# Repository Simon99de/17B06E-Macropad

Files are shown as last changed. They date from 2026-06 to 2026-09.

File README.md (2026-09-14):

# 17B06E-Macropad (by Simon99de)
> [!WARNING]
> Please note: The code is no longer being updated on GitHub!
> 
> The project has been moved to [Codeberg](https://codeberg.org/Simon99de/17B06E-Macropad)!

***
Eine deutsche Anleitung findest du auf meiner Website: [Simon99.de](https://simon99.de/blog/17b06e-macropad/)

It is a simple 4x4 (+1) numpad with 6 rotary encoders, 4x4 RGB LEDs, OLED display, and hot-swap keys.

You can customize all 6 encoders and 17 keys however you want. It also supports multiple layers (/pages), which means that a single key can do much more. (That's why the keyboard has 17 keys instead of 16.)

It can be an alternative to various keyboards such as Streamdeck+, Loupdeck Live, etc. if you don't need the screen behind the keys. In addition, the Macropad keyboard does not require any background software to function, which means increased compatibility.

Powered by QMK via Waveshare RP2040-Plus / Raspberry Pi Pico (1).

### What does 17B06E mean?
I chose the name 17B06E-Macropad because it describes everything the Macropad has. 17 Buttons + 6 Encoders. It also has RGB and a small OLED display.
The top button is used to switch profiles, giving you 16 x 4 (or more/less) buttons at your disposal, with the current profile shown on the display.

***

#### The old code is in the V1 branch.

#### But you should go to Codeberg! (link above)

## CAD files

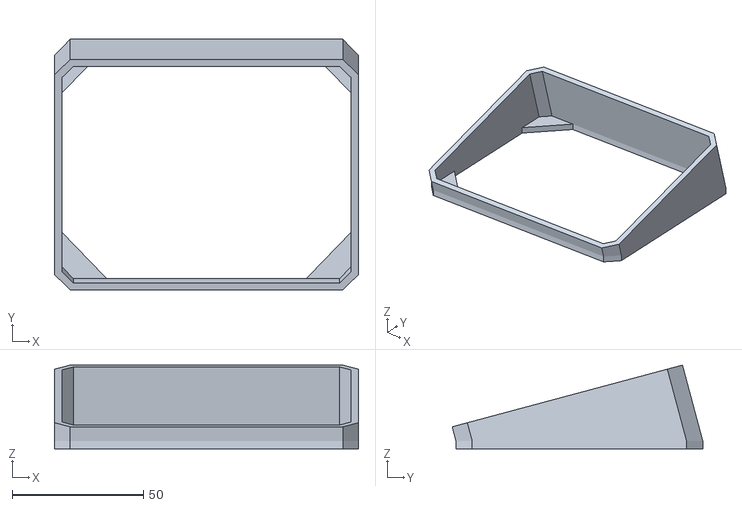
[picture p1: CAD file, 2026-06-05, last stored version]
case/17B06E-Macropad-Case-Foot_v1.stl
116.0 x 95.7 x 32.0

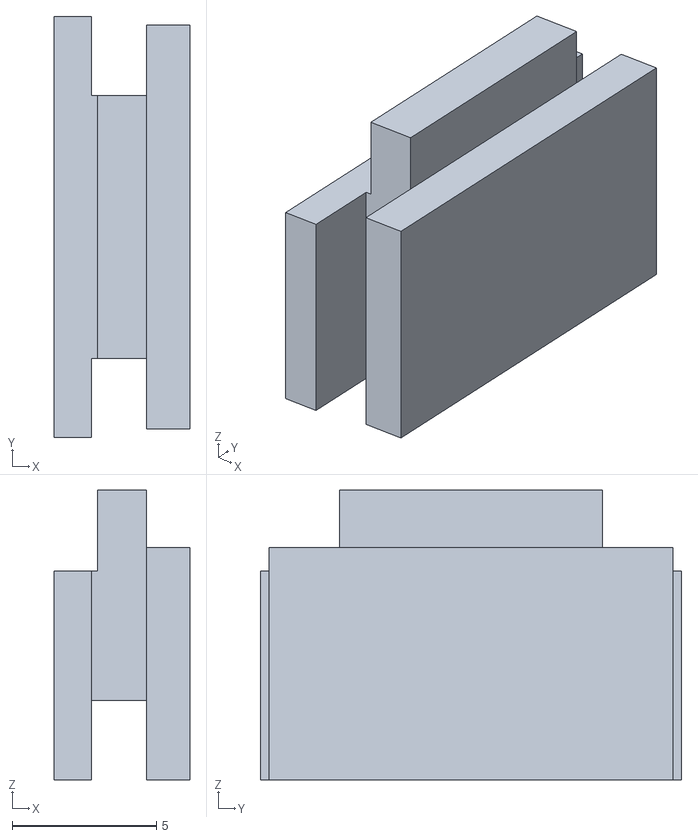
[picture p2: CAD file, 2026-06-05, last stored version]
case/mods/17B06E-Macropad-Case-Mod-USB-c-Cover_v1-hotswap-MCU.stl
4.70 x 14.6 x 10.1

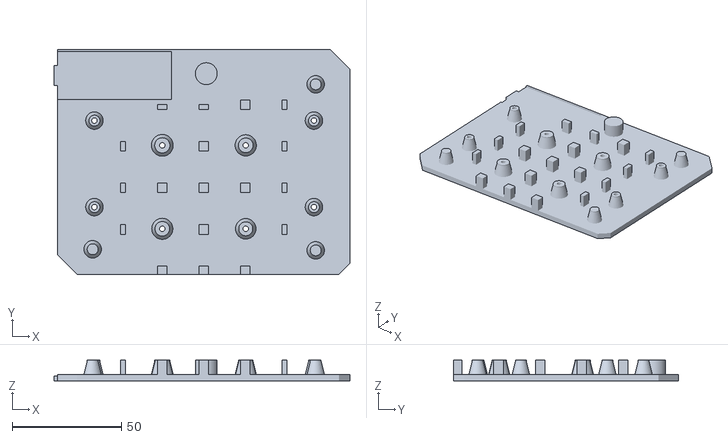
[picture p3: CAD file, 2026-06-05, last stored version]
case/17B06E-Macropad-Case-Cover_v1.stl
135.5 x 102.9 x 9.60

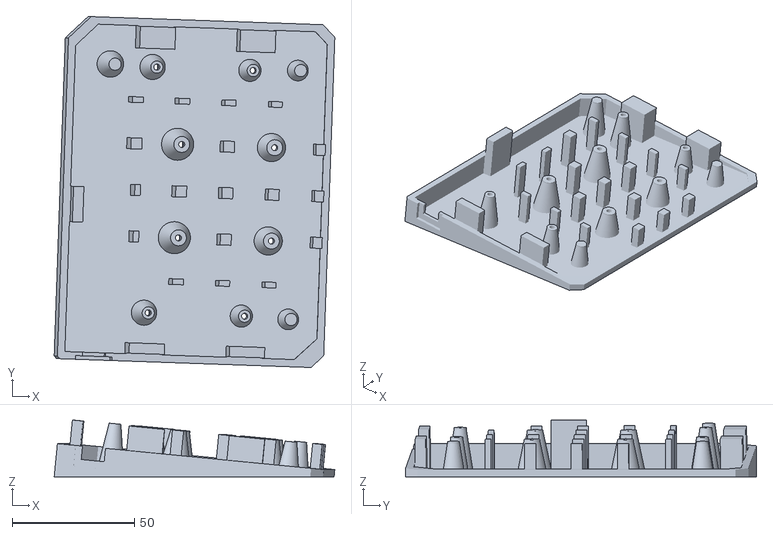
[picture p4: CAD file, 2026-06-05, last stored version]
case/mods/17B06E-Macropad-Case-Mod-Cover_v1-hotswap-MCU.stl
114.7 x 143.5 x 23.2

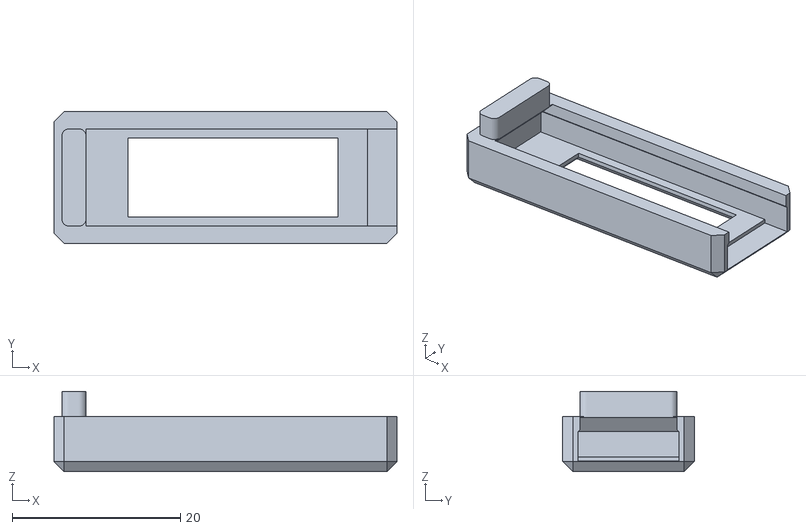
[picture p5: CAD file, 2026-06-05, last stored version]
case/17B06E-Macropad-Case-oLed-Display-Housing_v1.stl
40.8 x 15.6 x 9.55

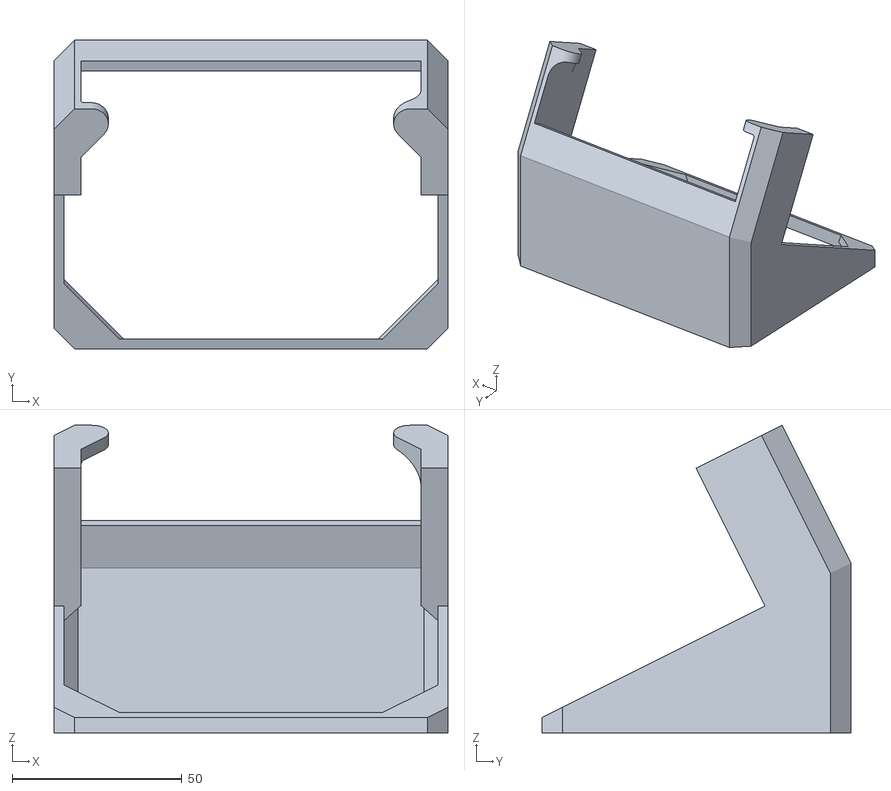
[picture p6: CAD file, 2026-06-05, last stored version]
case/mods/17B06E-Macropad_Mod_Scarlett-Solo-gen4-Top_Stand.stl
116.1 x 91.1 x 90.6

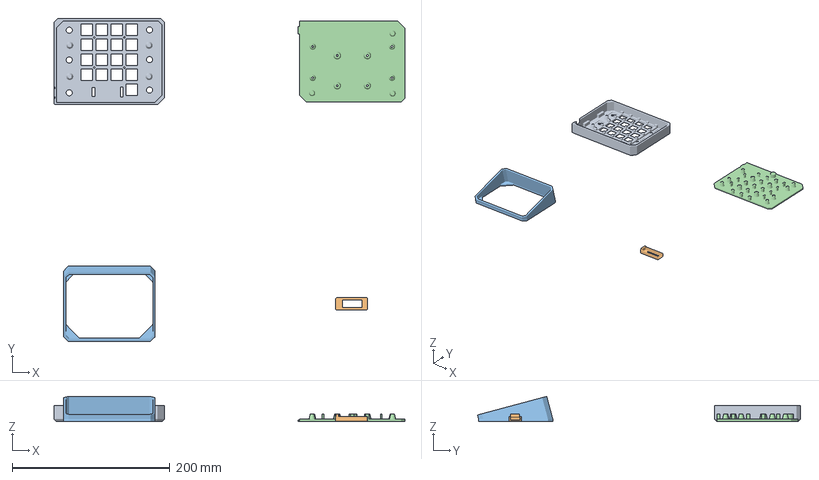
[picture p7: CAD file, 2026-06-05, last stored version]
case/17B06E-Macropad-Case.3mf
445.0 x 409.7 x 32.0 mm
17B06E-Macropad-Case-Front-Housing_v1.stl
17B06E-Macropad-Case-oLed-Display-Housing_v1.stl
17B06E-Macropad-Case-Foot_v1.stl
17B06E-Macropad-Case-Cover_v1.stl

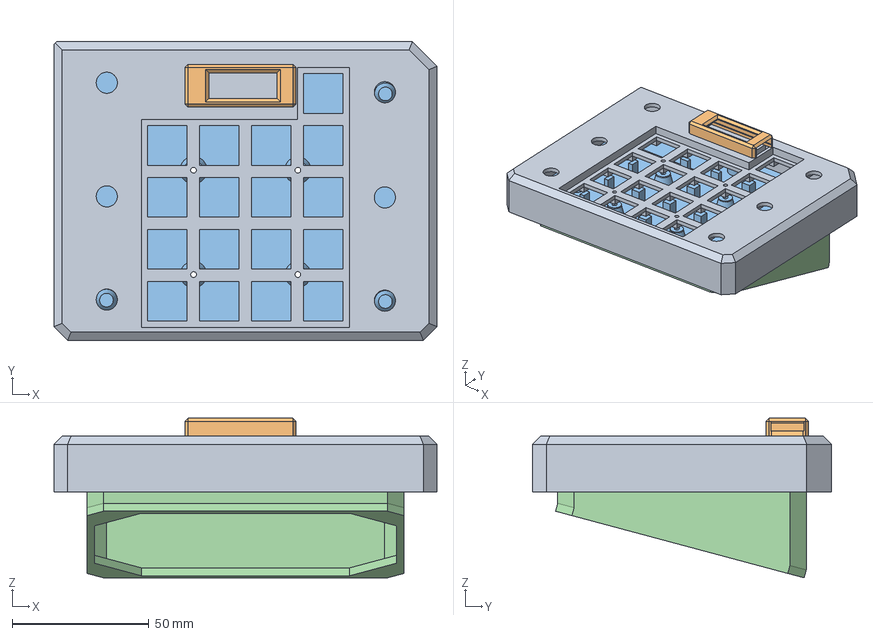
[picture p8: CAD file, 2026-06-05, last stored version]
case/17B06E-Macropad.FCStd
140.2 x 109.3 x 58.4 mm
Front-Housing_v1
oLed-Display-Housing_v1
Cover_v1
Foot_v1

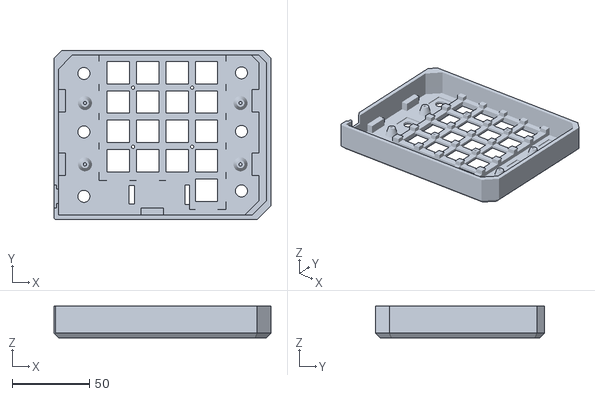
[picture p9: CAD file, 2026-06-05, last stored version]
case/17B06E-Macropad-Case-Front-Housing_v1.stl
140.2 x 109.3 x 20.5

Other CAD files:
case/mods/17B06E-Macropad_Mod_Scarlett-Solo-gen4.FCStd

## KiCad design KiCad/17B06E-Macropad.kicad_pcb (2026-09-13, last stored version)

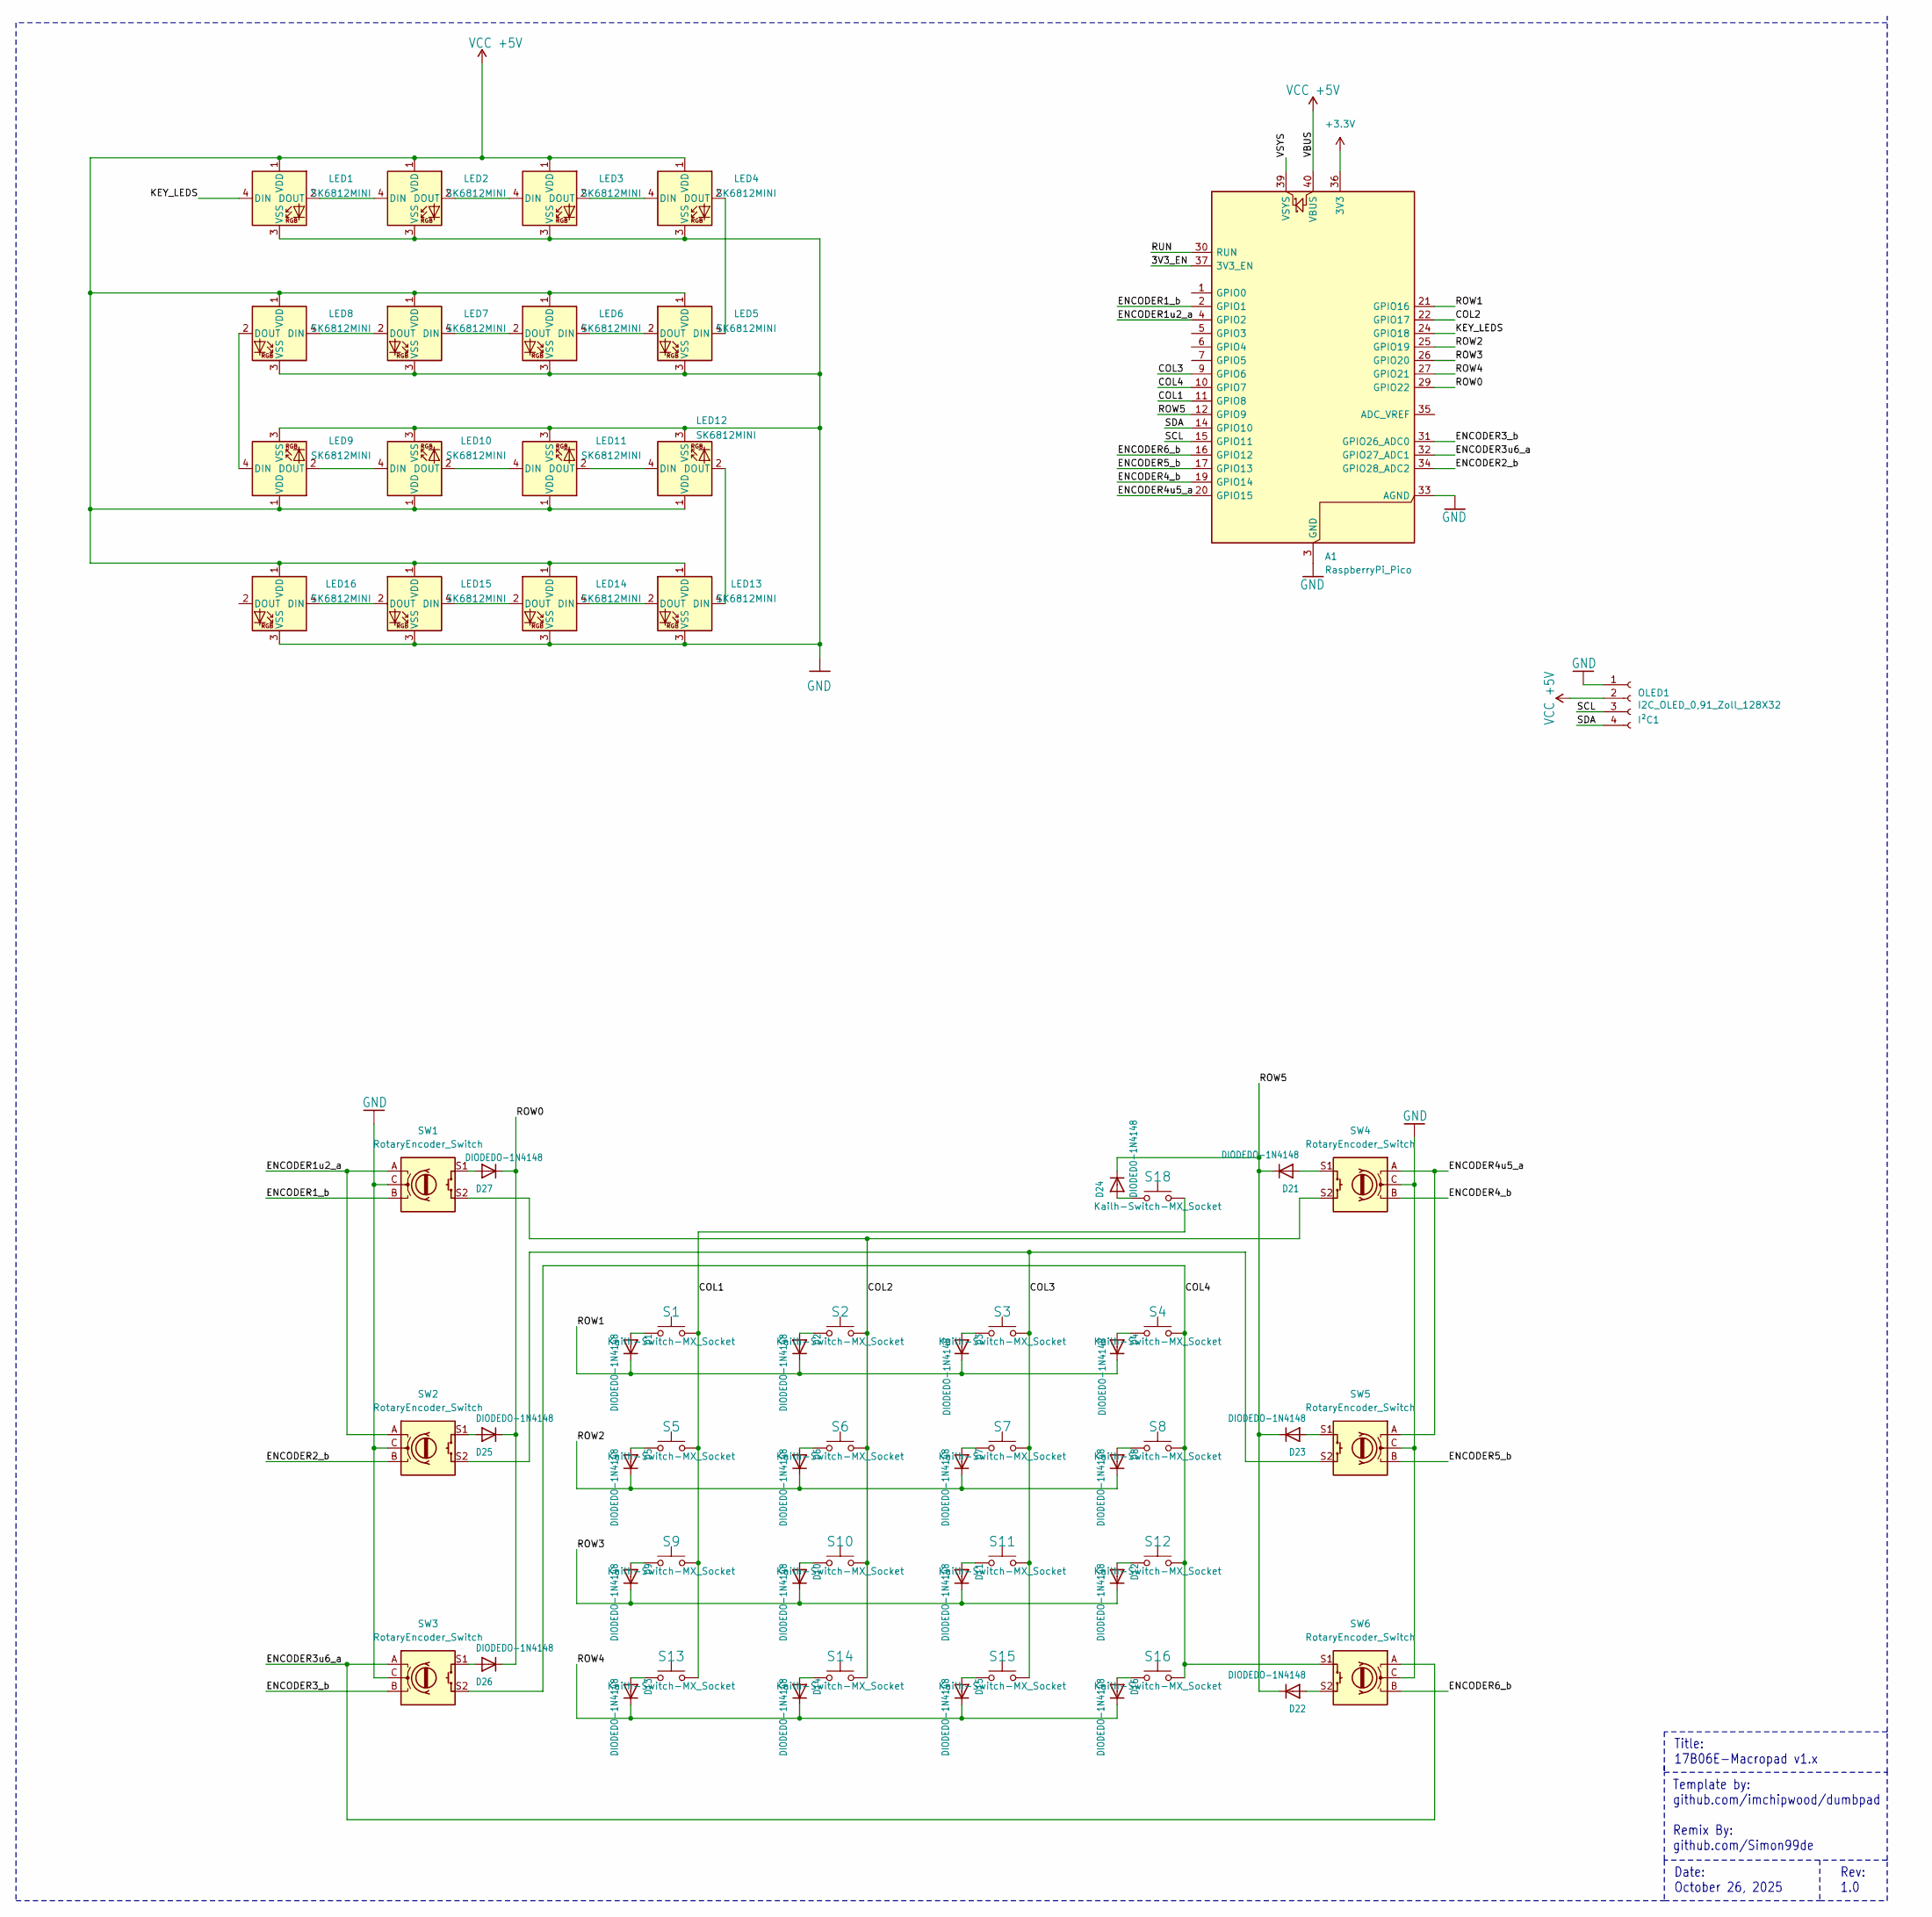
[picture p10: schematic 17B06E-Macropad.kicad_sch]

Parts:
A1: RaspberryPi_Pico; RaspberryPi_Pico_No_WIFI
D1, D2, D3, D4, D5, D6, D7, D8, D9, D10, D11, D12, D13, D14, D15, D16, D21, D22, D23, D24, D25, D26, D27: DIODEDO-1N4148; DO-1N4148
LED1, LED2, LED3, LED4, LED5, LED6, LED7, LED8, LED9, LED10, LED11, LED12, LED13, LED14, LED15, LED16: SK6812MINI; YS-SK6812MINI-E
OLED1: I2C_OLED_0,91_Zoll_128X32; OLED
S1, S2, S3, S4, S5, S6, S7, S8, S9, S10, S11, S12, S13, S14, S15, S16, S18: Kailh-Switch-MX_Socket; Kailh-CPG151101S11_MX_Socket-1.00u
SW1, SW2, SW3, SW4, SW5, SW6: RotaryEncoder_Switch; RotaryEncoder_Alps_EC11E-Switch_Vertical_H20mm

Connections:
/COL1: A1.11 (GPIO8), S1.2, S5.2, S9.2, S13.2, S18.2; also elsewhere on the board
/COL2: A1.22 (GPIO17), S2.2, S6.2, S10.2, S14.2, SW1.S2, SW4.S2; also elsewhere on the board
/COL3: A1.9 (GPIO6), S3.2, S7.2, S11.2, S15.2, SW2.S2, SW5.S2; also elsewhere on the board
/COL4: A1.10 (GPIO7), S4.2, S8.2, S12.2, S16.2, SW3.S2, SW6.S1; also elsewhere on the board
/ENCODER1_b: A1.2 (GPIO1), SW1.B; also elsewhere on the board
/ENCODER1u2_a: A1.4 (GPIO2), SW1.A, SW2.A; also elsewhere on the board
/ENCODER2_b: A1.34 (GPIO28_ADC2), SW2.B; also elsewhere on the board
/ENCODER3_b: A1.31 (GPIO26_ADC0), SW3.B; also elsewhere on the board
/ENCODER3u6_a: A1.32 (GPIO27_ADC1), SW3.A, SW6.A; also elsewhere on the board
/ENCODER4_b: A1.19 (GPIO14), SW4.B; also elsewhere on the board
/ENCODER4u5_a: A1.20 (GPIO15), SW4.A, SW5.A; also elsewhere on the board
/ENCODER5_b: A1.17 (GPIO13), SW5.B; also elsewhere on the board
/ENCODER6_b: A1.16 (GPIO12), SW6.B; also elsewhere on the board
/KEY_LEDS: A1.24 (GPIO18), LED1.4 (DIN); also elsewhere on the board
/ROW0: A1.29 (GPIO22), D25.C, D26.C, D27.C; also elsewhere on the board
/ROW1: A1.21 (GPIO16), D1.C, D2.C, D3.C, D4.C; also elsewhere on the board
/ROW2: A1.25 (GPIO19), D5.C, D6.C, D7.C, D8.C; also elsewhere on the board
/ROW3: A1.26 (GPIO20), D9.C, D10.C, D11.C, D12.C; also elsewhere on the board
/ROW4: A1.27 (GPIO21), D13.C, D14.C, D15.C, D16.C; also elsewhere on the board
/ROW5: A1.12 (GPIO9), D21.C, D22.C, D23.C, D24.C; also elsewhere on the board
/SCL: A1.15 (GPIO11), OLED1.3; also elsewhere on the board
/SDA: A1.14 (GPIO10), OLED1.4; also elsewhere on the board
GND: A1.3 (GND), A1.8 (GND), A1.13 (GND), A1.18 (GND), A1.23 (GND), A1.28 (GND), A1.33 (AGND), A1.38 (GND), LED1.3 (VSS), LED2.3 (VSS), LED3.3 (VSS), LED4.3 (VSS), LED5.3 (VSS), LED6.3 (VSS), LED7.3 (VSS), LED8.3 (VSS), LED9.3 (VSS), LED10.3 (VSS), LED11.3 (VSS), LED12.3 (VSS), LED13.3 (VSS), LED14.3 (VSS), LED15.3 (VSS), LED16.3 (VSS), OLED1.1, SW1.C, SW2.C, SW3.C, SW4.C, SW5.C, SW6.C; also elsewhere on the board
unnamed: D1.A, S1.1
unnamed: D2.A, S2.1
unnamed: D3.A, S3.1
unnamed: D4.A, S4.1
unnamed: D5.A, S5.1
unnamed: D6.A, S6.1
unnamed: D7.A, S7.1
unnamed: D8.A, S8.1
unnamed: D9.A, S9.1
unnamed: D10.A, S10.1
unnamed: D11.A, S11.1
unnamed: D12.A, S12.1
unnamed: D13.A, S13.1
unnamed: D14.A, S14.1
unnamed: D15.A, S15.1
unnamed: D16.A, S16.1
unnamed: D21.A, SW4.S1
unnamed: D22.A, SW6.S2
unnamed: D23.A, SW5.S1
unnamed: D24.A, S18.1
unnamed: D25.A, SW2.S1
unnamed: D26.A, SW3.S1
unnamed: D27.A, SW1.S1
unnamed: LED1.2 (DOUT), LED2.4 (DIN)
unnamed: LED2.2 (DOUT), LED3.4 (DIN)
unnamed: LED3.2 (DOUT), LED4.4 (DIN)
unnamed: LED4.2 (DOUT), LED5.4 (DIN)
unnamed: LED5.2 (DOUT), LED6.4 (DIN)
unnamed: LED6.2 (DOUT), LED7.4 (DIN)
unnamed: LED7.2 (DOUT), LED8.4 (DIN)
unnamed: LED8.2 (DOUT), LED9.4 (DIN)
unnamed: LED9.2 (DOUT), LED10.4 (DIN)
unnamed: LED10.2 (DOUT), LED11.4 (DIN)
unnamed: LED11.2 (DOUT), LED12.4 (DIN)
unnamed: LED12.2 (DOUT), LED13.4 (DIN)
unnamed: LED13.2 (DOUT), LED14.4 (DIN)
unnamed: LED14.2 (DOUT), LED15.4 (DIN)
unnamed: LED15.2 (DOUT), LED16.4 (DIN)
VCC +5V: A1.40 (VBUS), LED1.1 (VDD), LED2.1 (VDD), LED3.1 (VDD), LED4.1 (VDD), LED5.1 (VDD), LED6.1 (VDD), LED7.1 (VDD), LED8.1 (VDD), LED9.1 (VDD), LED10.1 (VDD), LED11.1 (VDD), LED12.1 (VDD), LED13.1 (VDD), LED14.1 (VDD), LED15.1 (VDD), LED16.1 (VDD), OLED1.2; also elsewhere on the board

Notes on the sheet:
Rev: 1.0
Template by: github.com/imchipwood/dumbpad Remix By: github.com/Simon99de
Title: 17B06E-Macropad v1.x
Date: October 26, 2025

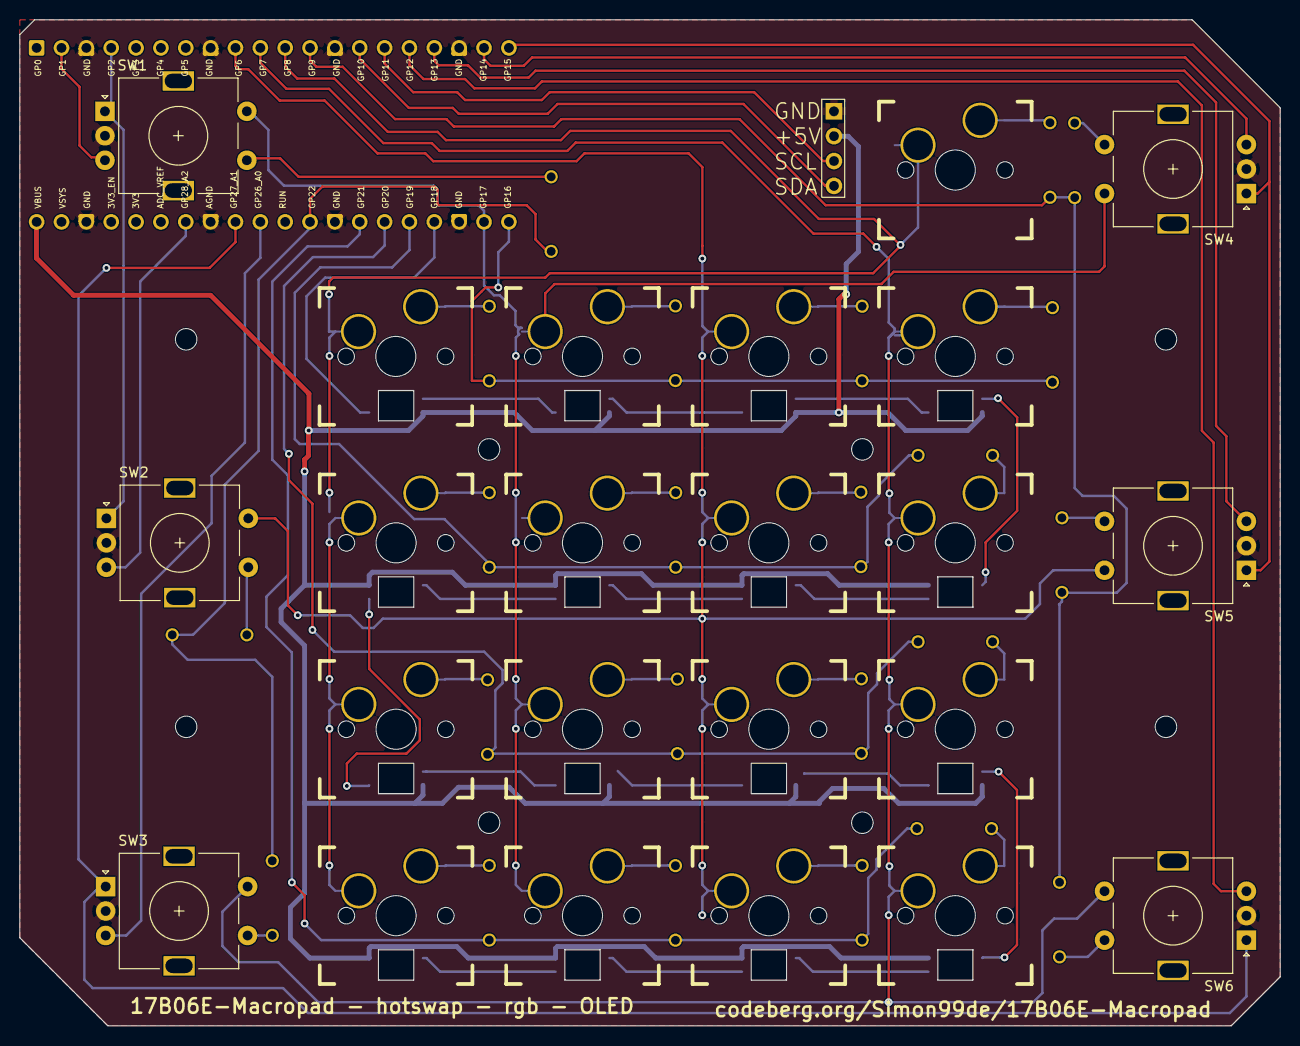
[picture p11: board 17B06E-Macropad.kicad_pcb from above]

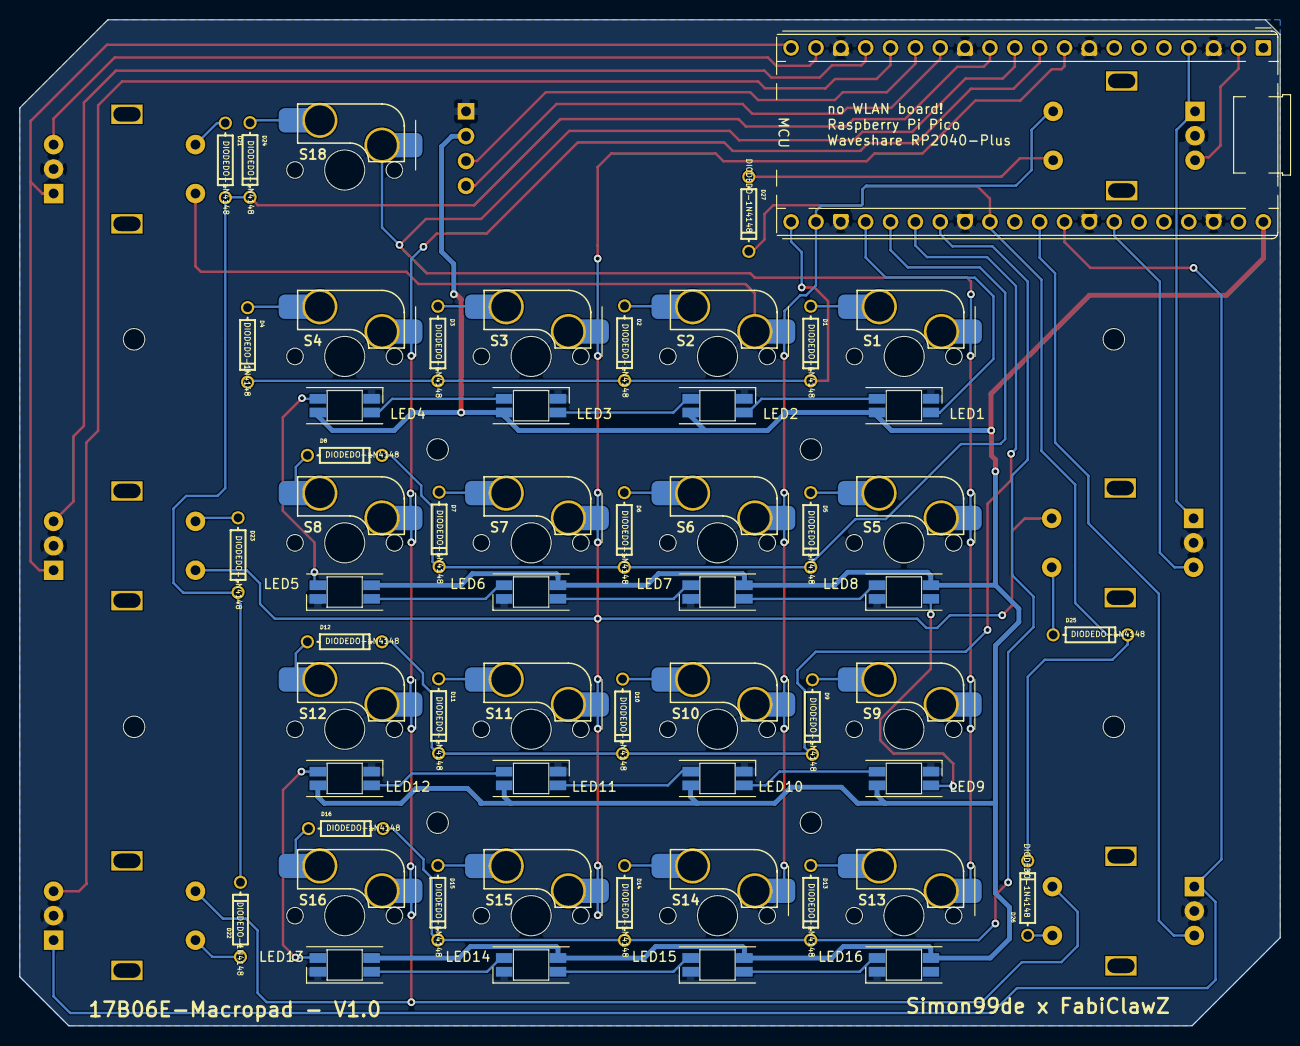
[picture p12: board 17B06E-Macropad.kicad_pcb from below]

Board: 2 copper layers, 128.8 x 102.8 mm, 64 parts (57 on the bottom side), 62 nets.

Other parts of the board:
MCU: RaspberryPi_Pico; RaspberryPi_Pico_No_WIFI

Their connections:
/COL1: MCU.11 (GPIO8); also elsewhere on the board
/COL2: MCU.22 (GPIO17); also elsewhere on the board
/COL3: MCU.9 (GPIO6); also elsewhere on the board
/COL4: MCU.10 (GPIO7); also elsewhere on the board
/ENCODER1_b: MCU.2 (GPIO1); also elsewhere on the board
/ENCODER1u2_a: MCU.4 (GPIO2); also elsewhere on the board
/ENCODER2_b: MCU.34 (GPIO28_ADC2); also elsewhere on the board
/ENCODER3_b: MCU.31 (GPIO26_ADC0); also elsewhere on the board
/ENCODER3u6_a: MCU.32 (GPIO27_ADC1); also elsewhere on the board
/ENCODER4_b: MCU.19 (GPIO14); also elsewhere on the board
/ENCODER4u5_a: MCU.20 (GPIO15); also elsewhere on the board
/ENCODER5_b: MCU.17 (GPIO13); also elsewhere on the board
/ENCODER6_b: MCU.16 (GPIO12); also elsewhere on the board
/KEY_LEDS: MCU.24 (GPIO18); also elsewhere on the board
/ROW0: MCU.29 (GPIO22); also elsewhere on the board
/ROW1: MCU.21 (GPIO16); also elsewhere on the board
/ROW2: MCU.25 (GPIO19); also elsewhere on the board
/ROW3: MCU.26 (GPIO20); also elsewhere on the board
/ROW4: MCU.27 (GPIO21); also elsewhere on the board
/ROW5: MCU.12 (GPIO9); also elsewhere on the board
/SCL: MCU.15 (GPIO11); also elsewhere on the board
/SDA: MCU.14 (GPIO10); also elsewhere on the board
GND: MCU.3 (GND), MCU.8 (GND), MCU.13 (GND), MCU.18 (GND), MCU.23 (GND), MCU.28 (GND), MCU.33 (AGND), MCU.38 (GND); also elsewhere on the board
VCC +5V: MCU.40 (VBUS); also elsewhere on the board

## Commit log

2025-10-26 PCB layout KiCad data
    [17B06E-Macropad.kicad_pcb, 17B06E-Macropad.kicad_sch]
2025-10-30 Various adjustments/improvements
    [17B06E-Macropad.kicad_pcb, 17B06E-Macropad.kicad_sch]
2025-10-30 Encoder better labeled as a/b in the schematic
    [17B06E-Macropad.kicad_pcb, 17B06E-Macropad.kicad_sch]
2025-11-01 various changes
    holes changed,
    schematic correctly arranged,
    and even more
    [17B06E-Macropad.kicad_pcb, 17B06E-Macropad.kicad_sch]
2025-11-01 Delete KiCad/17B06E-Macropad.pretty/LED_3MM.kicad_mod
    is not needed/is too much
2025-11-01 Delete KiCad/17B06E-Macropad.pretty/AXIAL-0.3.kicad_mod
    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
2025-11-01 Delete KiCad/17B06E-Macropad.pretty/TACTILE_SWITCH_PTH_6.0MM.kicad_mod
    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
2025-11-01 Pin description added for MCU
    [17B06E-Macropad.kicad_pcb]
2025-11-01 PCB manufactures Data
2025-11-09 Update README.md
    More information added and prepared for links to be inserted.
2025-11-11 Update rgb mounting
2025-11-16 Update README.md
    forgot the screws for the housing
2025-11-17 Update
    encoder matrix image added + example
2025-11-21 stl + 3mf file uploaded
    stl + 3mf file uploaded for testing, prior to release.
    [17B06E-Macropad-Case-Cover_v1.stl, 17B06E-Macropad-Case-Foot_v1.stl, 17B06E-Macropad-Case-Front-Housing_v1.stl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]
2025-11-21 add oled +led picture
2025-11-21 add oled + led Picture
2025-11-22 test files!
    [17B06E-Macropad-Case-Mod-Cover_v1-hotswap-MCU.stl, 17B06E-Macropad-Case-Mod-USB-c-Cover_v1-hotswap-MCU.stl]
2025-11-28 update
    slightly enlarged to ensure a better fit
    [17B06E-Macropad-Case-Cover_v1.stl, 17B06E-Macropad-Case-Foot_v1.stl, 17B06E-Macropad-Case-Front-Housing_v1.stl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]
2025-12-21 add images
    add hotswap MCU housing images
2025-12-21 alignment changed
    [17B06E-Macropad-Case-Foot_v1.stl, 17B06E-Macropad-Case-Front-Housing_v1.stl, 17B06E-Macropad-Case-oLed-Display-Housing_v1.stl]
2025-12-21 Update README.md
    links to printables etc. adjusted
2026-09-13 URL to Codeberg
    Repo migration
    [17B06E-Macropad.kicad_pcb]
